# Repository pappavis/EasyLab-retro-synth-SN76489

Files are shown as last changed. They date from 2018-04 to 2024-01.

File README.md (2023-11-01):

## Chiptunes afspeel met Arduino ##
Lang gelede in die 1980's het ons grootgeword met 8-bit rekenaars soos BBC Micro B. Herleef die glorie en gebruik 'n BBC Micro geluidchip op Arduino | Raspberry Pi | Microbit.<br/>
<br/>
door: Michiel Erasmus<br/>
<br/>

## KiCAD 3d preview:
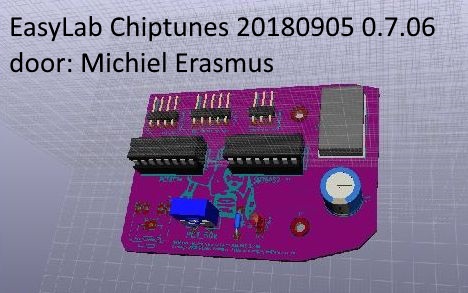
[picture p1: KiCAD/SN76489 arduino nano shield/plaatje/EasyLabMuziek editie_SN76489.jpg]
<br/>
<br/>

# User review
Buy online https://www.tindie.com/products/VliegendeVogel/arduino-soundcard-i2c-and-bbc-microbit-with-mml/

## Egte versie
Finale versie 0.7.06 <br>
<br/>

<br/>

## EasyLab4Kids
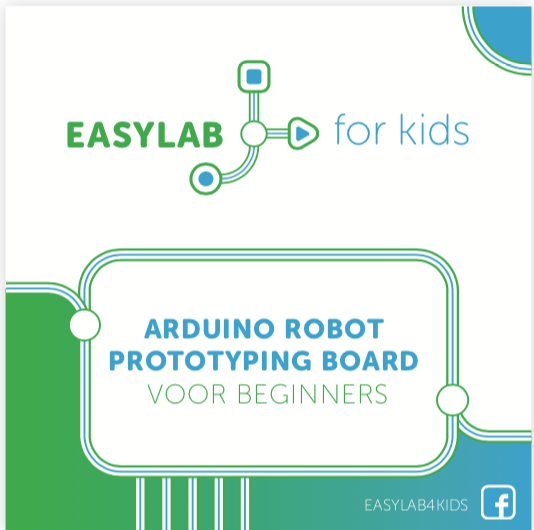
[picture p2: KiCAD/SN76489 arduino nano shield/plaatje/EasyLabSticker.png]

<br/><br/>
#e4kdenhaag<br/>

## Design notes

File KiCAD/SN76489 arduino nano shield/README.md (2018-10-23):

# EasyLab Muziek Editie #

Dit is 'n [Arduino][] shield vir [KiCad][] om muziek mee af te speel met gebruik van [SN76489][] geluids chip. <br/>
Die Sn76489 gebruik 'n 4.0000Mhz clock wat, of hardware clock osscilator kan wees, of gegenereerd met <a href="https://github.com/maxint-rd/FastPwmPin" target="_blank">FastPwmPin</a> van Maxint-RD.<br/>
<br/>
Features;<br/>
 - I2C aansluiting.<br/>
 - Gebruik arduino as clock op IO-poort 8.<br/>
 - Speel musiek af met MmlMusicPWM ook van MaxInt-RD.<br/>
 - Werkt met Arduino Nano, mega, Attiny85, D-MOS1 WiFi, Digispark USB, ESP8266-01 WiFi enz.



[KiCad]: http://www.kicad-pcb.org
[Arduino]: http://arduino.cc/
[SN76489]: https://nl.wikipedia.org/wiki/SN76489

## Hoe om te gebruik ##
 * Download Arduino IDE
 * Download en installeer Arduino biblioteek https://github.com/maxint-rd/mxUnifiedSN76489
 * Download en installeer Arduino biblioteek https://github.com/maxint-rd/mxUnifiedPCF8574
 * Met Arduino IDE. open voorbeeld Arduino/SN76489_met_PCF8574_arduino_clock_20180131.ino
  
## In deze argief ##

* KiCAD ontwerp
    * Die skema  en KiCAD model om 'n SN76489 geluidschip te gebruik.
* Printplaat schema
    * TODO -- gerber vir produksie
* 3D model
    * Voorbeeld van die model
* Bill of Materials
    * TODO
    
## License ##

Dit is 'n projek met GNU GPL version 3-lisensie.
usage of this PCB design should credit me as author. Thanks!

## Ontwikkelaar ##
2017-12-07 Origineel release<br/>
2017-06-02 Standalone I2C versie gebruikt.<br/>

<br/>\
#EasyLabMuziek #s4kdenhaag<br/>

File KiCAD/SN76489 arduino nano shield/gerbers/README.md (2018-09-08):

printplaat 20180602 0.6



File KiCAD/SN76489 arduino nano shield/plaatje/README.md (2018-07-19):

printplaat revisie 20180719 0.7.03

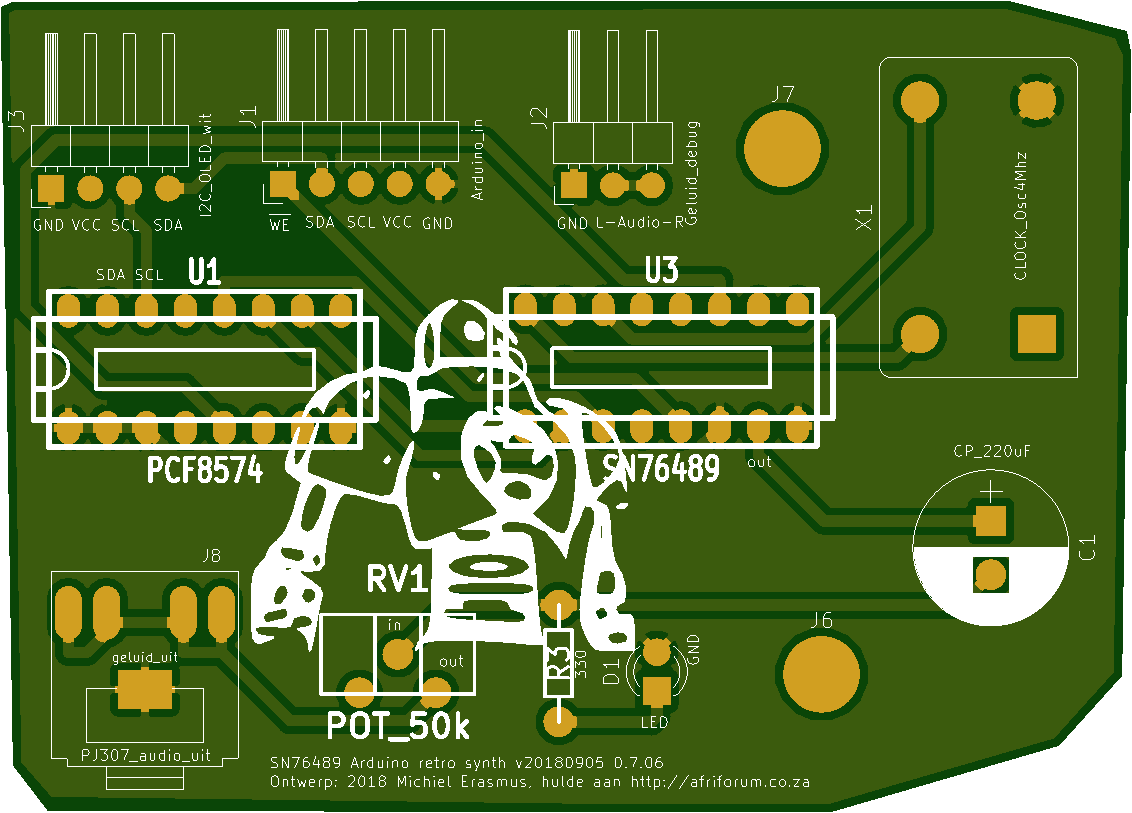
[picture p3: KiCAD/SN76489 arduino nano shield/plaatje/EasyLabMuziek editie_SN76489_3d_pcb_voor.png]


<br/>
<br/>
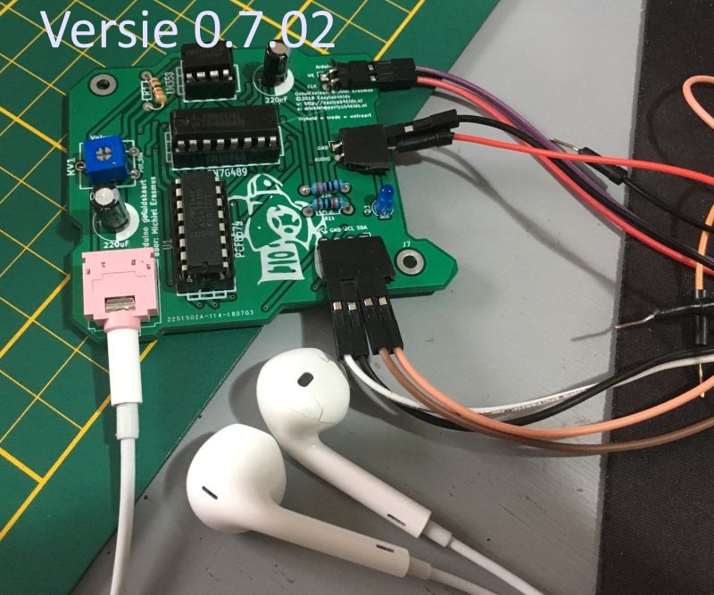
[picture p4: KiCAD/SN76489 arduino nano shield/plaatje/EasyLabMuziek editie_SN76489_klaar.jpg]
<br/>

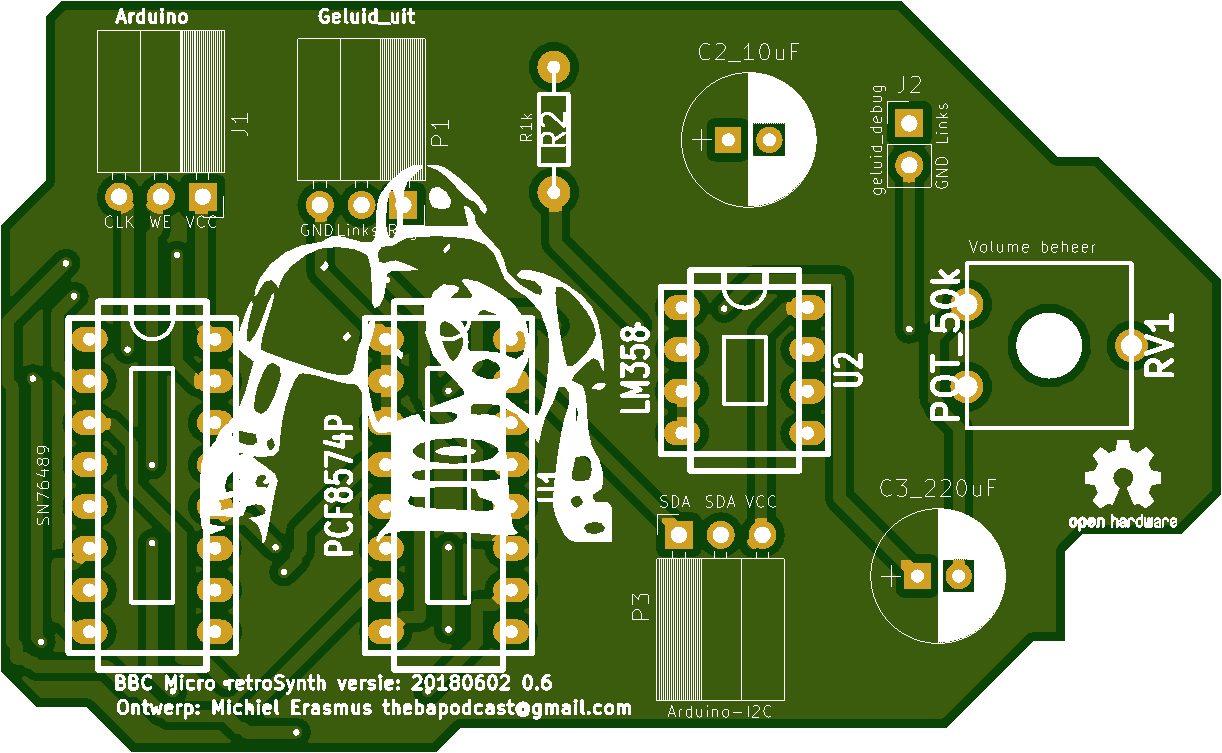
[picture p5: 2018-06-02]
KiCAD/SN76489 arduino nano shield/plaatje/EasyLabMuziek editie_SN76489_pcb_0.5_voor.png

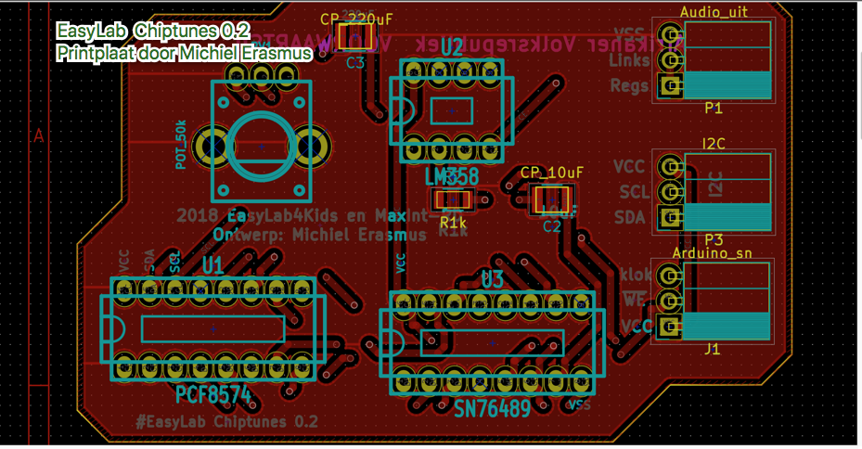
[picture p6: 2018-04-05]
KiCAD/SN76489 arduino nano shield/plaatje/EasyLabMuziek editie_SN76489_pcb.png

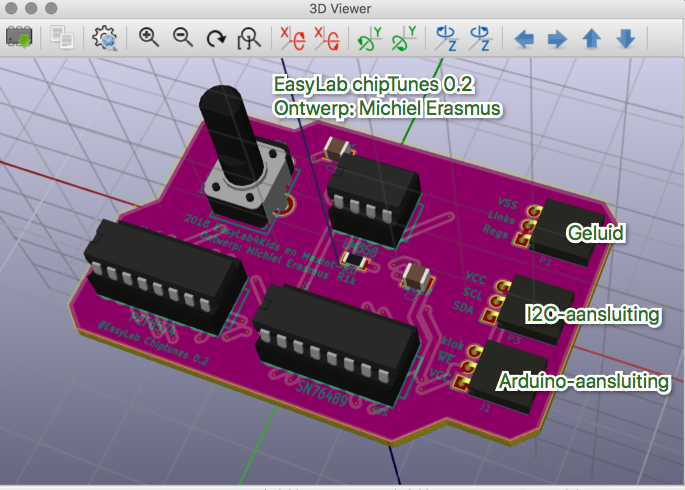
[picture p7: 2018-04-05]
KiCAD/SN76489 arduino nano shield/plaatje/EasyLabMuziek editie_SN76489_3d_0.2.png

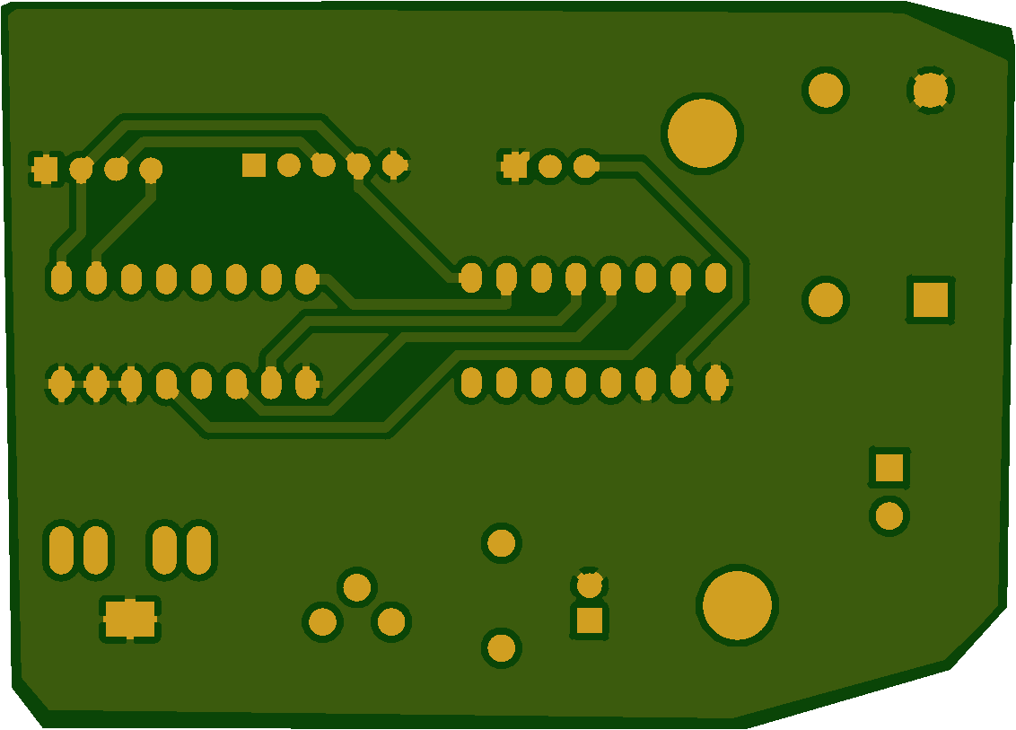
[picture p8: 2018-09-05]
KiCAD/SN76489 arduino nano shield/plaatje/EasyLabMuziek editie_SN76489_3d_pcb_agter.png

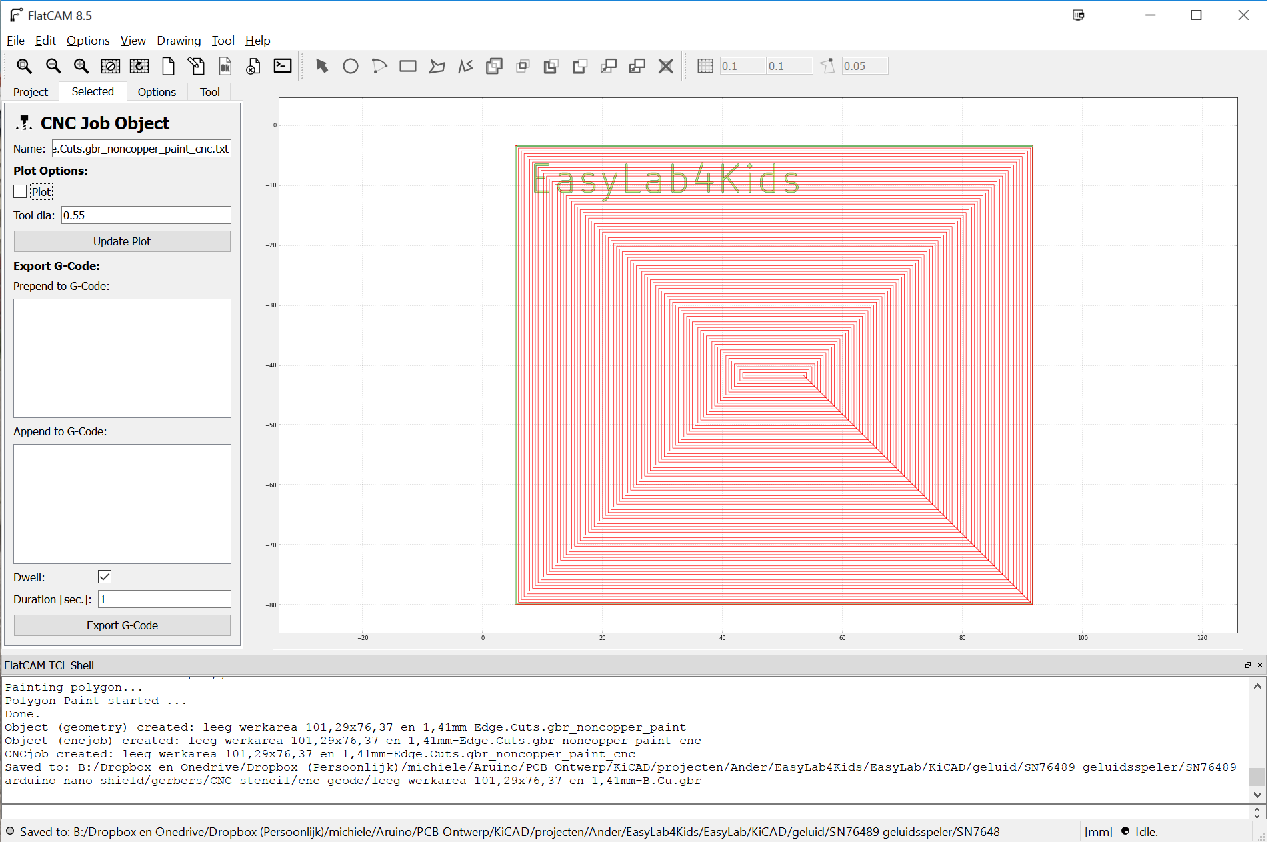
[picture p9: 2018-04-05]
KiCAD/SN76489 arduino nano shield/gerbers/CNC_stencil/leeg werkarea 101,29x76,37 en 1,41mm-Edge.Cuts.png

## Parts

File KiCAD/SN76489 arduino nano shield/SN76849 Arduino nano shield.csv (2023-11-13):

Id | Designator | Footprint | Quantity | Designation | Supplier and ref
1 | P1 | Jack_3.5mm_CUI_SJ1-3523N_Horizontal | 1 | TRS_JACK
2 | J5 | Sovjet_simpits_logo01 | 1 | LOGO
3 | U2 | DIP-8_W7.62mm | 1 | LM386
4 | J2 | PinHeader_1x03_P2.54mm_Vertical | 1 | audio_debug
5 | RV2 | Potentiometer_Bourns_3339P_Vertical | 1 | Pot_10k
6 | C2 | C_Disc_D3.4mm_W2.1mm_P2.50mm | 1 | 250uF
7 | J4 | PinHeader_1x06_P2.54mm_Vertical | 1 | ESP32Conn
8 | U1 | DIP-16_W7.62mm | 1 | PCF8574
9 | U3 | DIP-16_W7.62mm | 1 | SN76489
10 | J3 | PinHeader_1x04_P2.54mm_Horizontal | 1 | OLED_wit

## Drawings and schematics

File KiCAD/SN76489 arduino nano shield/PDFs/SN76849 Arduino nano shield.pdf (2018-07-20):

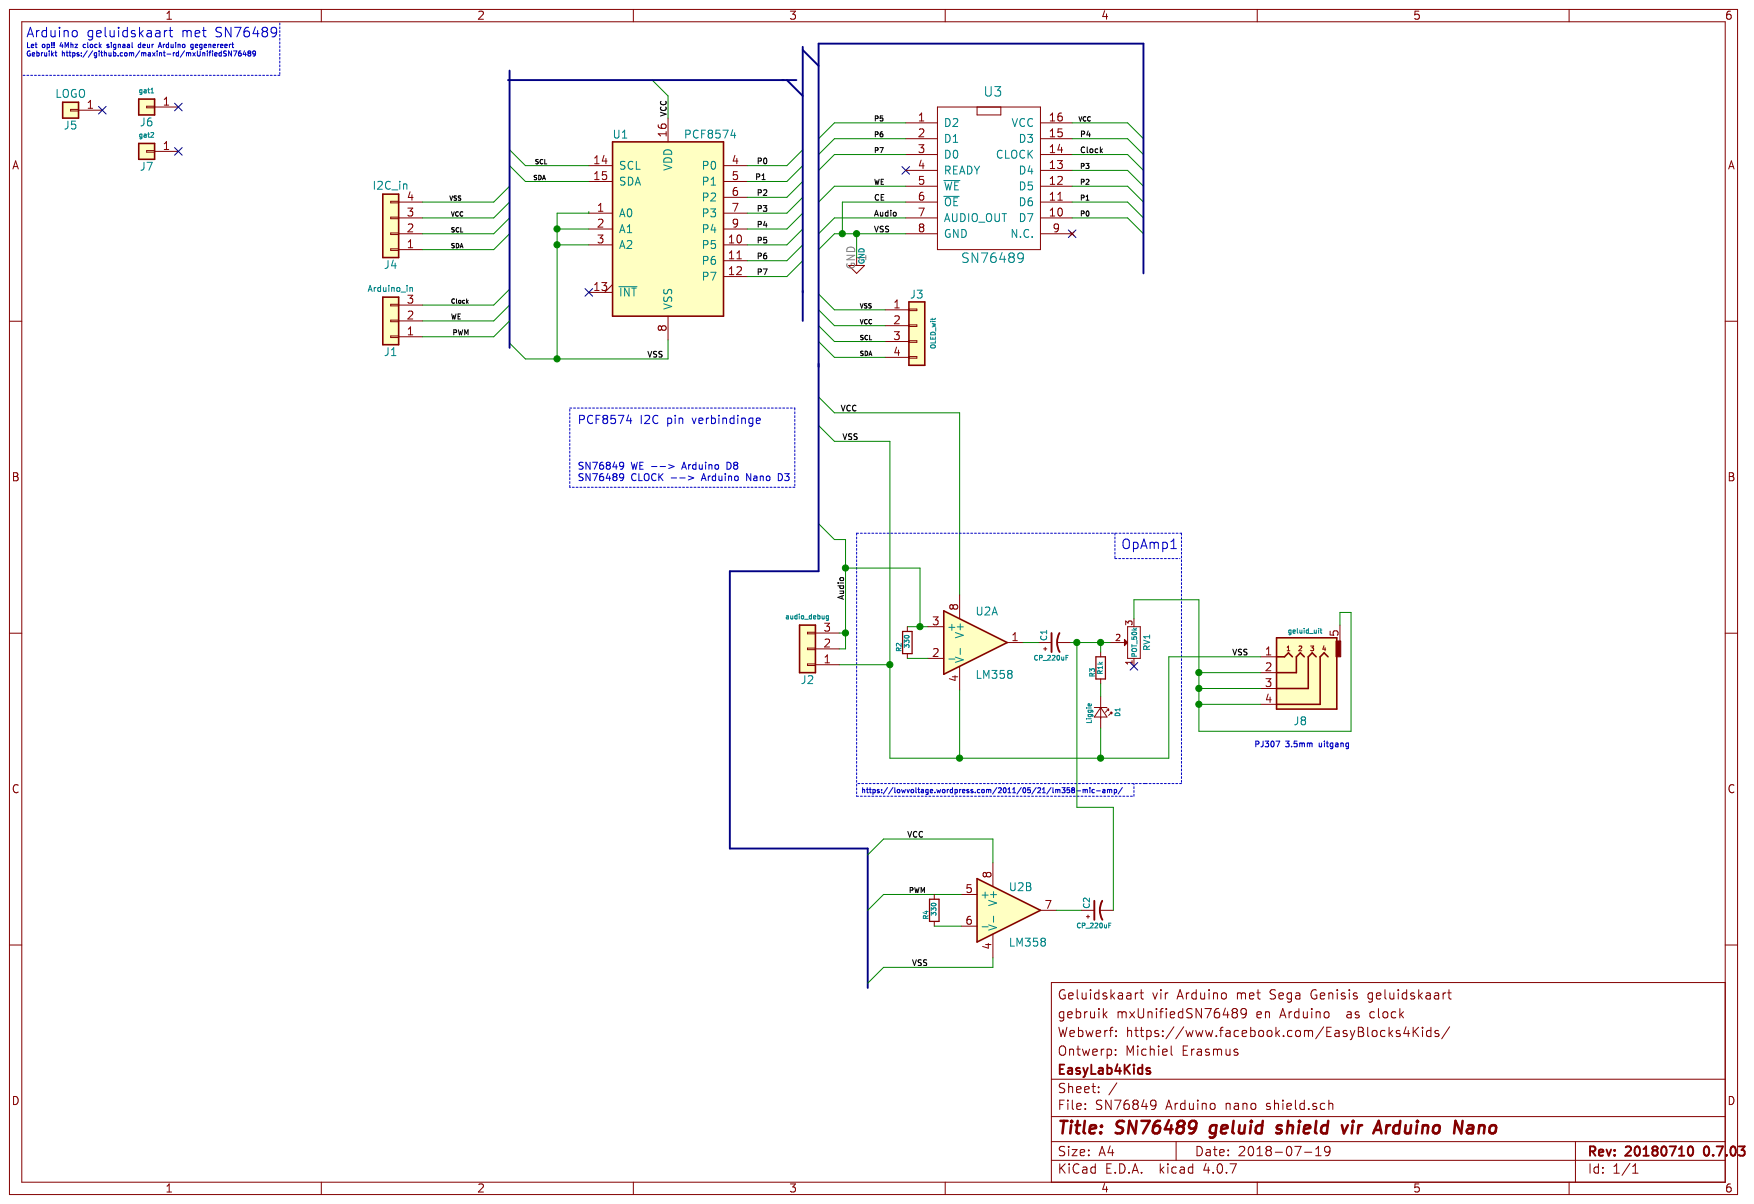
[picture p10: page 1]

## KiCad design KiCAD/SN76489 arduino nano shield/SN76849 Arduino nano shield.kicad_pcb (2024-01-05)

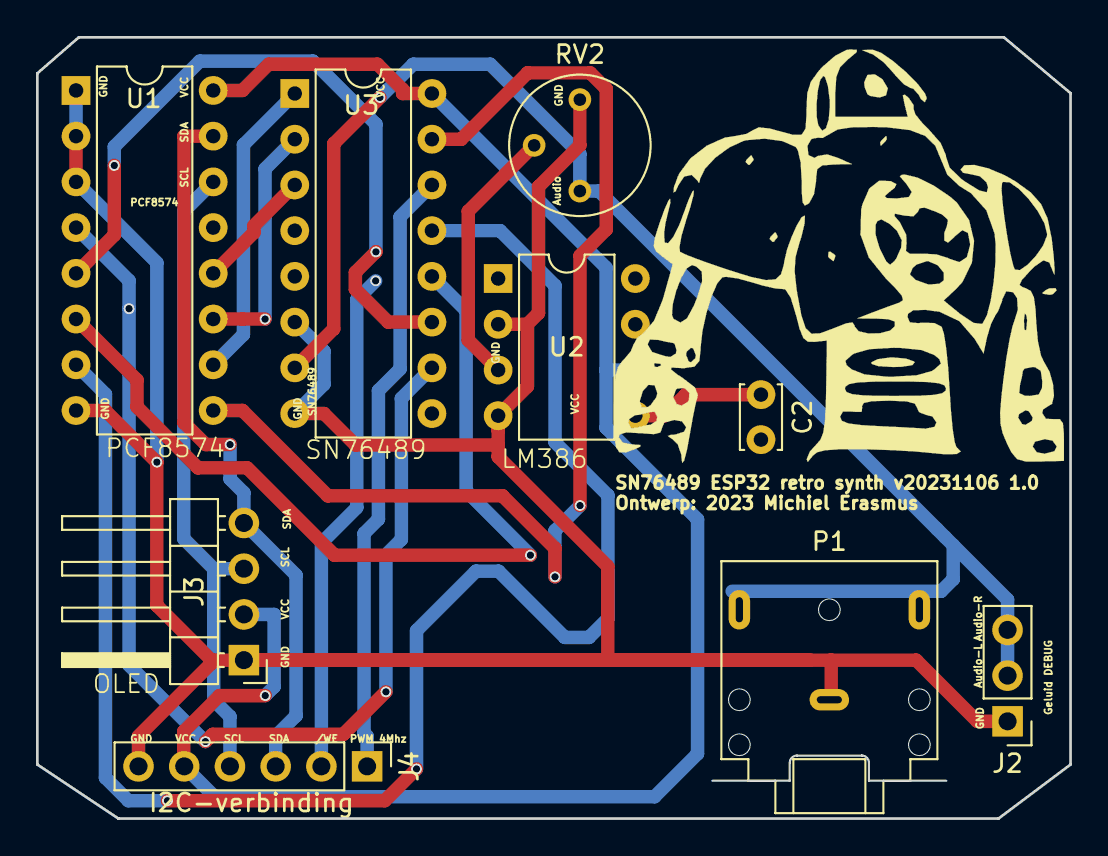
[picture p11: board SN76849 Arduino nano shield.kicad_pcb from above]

Board: 2 copper layers, 57.4 x 43.4 mm, 10 parts (0 on the bottom side), 16 nets.

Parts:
C2: 250uF; C_Disc_D3.4mm_W2.1mm_P2.50mm
J2: audio_debug; PinHeader_1x03_P2.54mm_Vertical
J3: OLED_wit; PinHeader_1x04_P2.54mm_Horizontal
J4: ESP32Conn; PinHeader_1x06_P2.54mm_Vertical
J5: LOGO; Sovjet_simpits_logo01
P1: TRS_JACK; Jack_3.5mm_CUI_SJ1-3523N_Horizontal
RV2: Pot_10k; Potentiometer_Bourns_3339P_Vertical
U1: PCF8574; DIP-16_W7.62mm
U2: LM386; DIP-8_W7.62mm
U3: SN76489; DIP-16_W7.62mm

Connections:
/Audio: J2.2, J2.3, RV2.1, U3.7 (AUDIO_OUT)
/Clock: J4.1, U3.14 (CLOCK)
/P0: U1.4 (P0), U3.10 (D7)
/P1: U1.5 (P1), U3.11 (D6)
/P2: U1.6 (P2), U3.12 (D5)
/P3: U1.7 (P3), U3.13 (D4)
/P4: U1.9 (P4), U3.15 (D3)
/P5: U1.10 (P5), U3.1 (D2)
/P6: U1.11 (P6), U3.2 (D1)
/P7: U1.12 (P7), U3.3 (D0)
/SCL: J3.3, J4.4, U1.14 (SCL)
/SDA: J3.4, J4.3, U1.15 (SDA)
GND: J2.1, J3.1, J4.6, RV2.3, U1.1 (A0), U1.2 (A1), U1.3 (A2), U1.8 (VSS), U2.2 (-), U2.4 (GND), U3.8 (GND)
unnamed: C2.1, U2.5
unnamed: RV2.2, U2.3 (+)
VCC: J3.2, J4.5, U1.16 (VDD), U2.6 (V+), U3.16 (VCC)

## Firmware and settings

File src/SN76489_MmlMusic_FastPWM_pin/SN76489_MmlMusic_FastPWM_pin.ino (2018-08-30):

// SN76489 retro synth voorbeeld
// versie: 20180807 0.7.05
// dit voorbeeld gebruik die Arduino om 4 Mhz clock signaal te genereren.
// sien afhanklikhede: https://github.com/maxint-rd?tab=repositories
// Arduino pin 4 = NotWE
// Arduino pin 3 = FastPWM Klok signaal

#define CLK_IOport  3
#define NotWEport   4

/*
 * mxUnifiedSN76489 MML Music
 * mxUnifiedSN76489 library example for Arduino IDE
 * 
 * Tbis example demonstrates playing MML music on the
 * SN76489 sound generator.
 * Using the mxUnifiedIO libraries, The SN76489 can be connected
 * to the MCU (e.g. Arduino Uno or ESP8266) via a shift
 * register or an I2C I/O expander.
 * 
 * For more information see: 
 *     https://github.com/maxint-rd/mxUnifiedSN76489
 *     https://github.com/maxint-rd/mxUnifiedIO
 *     https://github.com/maxint-rd/MmlMusic
 *
 * Made by MMOLE (@maxint-rd) 2017
 * 
 * For more MML music go to http://www.archeagemmllibrary.com/
 */

// Include header files for the used libraries
#include <mxUnifiedPCF8574.h>     // Use the PCF8574/8575 I/O-expander
//#include <mxUnified74HC595.h>   // use the 74HC595 shift-register
#include <mxUnifiedSN76489.h>
#include <MmlMusic.h>
// #include <FastPwmPin.h>

#if defined(MXUNIFIED_ATTINY)
  // ATtiny85 has no regular hardware serial. You can use TinyDebugSerial (TX=3) or software serial
  // For more info see  http://www.ernstc.dk/arduino/tinycom.html
  //#include <SoftwareSerial.h>
  //SoftwareSerial mySerial(4, 3); // RX, TX

  #include <TinyDebugSerial.h>
  TinyDebugSerial mySerial = TinyDebugSerial();   // Debug TX on PB3, no RX, only 9600, 38400 or 115200
  #define Serial mySerial
#endif

// When using a PCF8574/8575 I/O-expander, these connections and definitions can be used.
// Hardware I2C on ESP8266/D1-mini: SCL=GPIO5/D1, SDA=GPIO4/D2

// Use the PCF8574/8575 I/O-expander
mxUnifiedPCF8575 unio = mxUnifiedPCF8575(0x38);     // use the PCF875 I2C output expander on address 0x38

// define the pins used and initialize the mxUnifiedSN76489 object
// mxUnifiedSN76489 sound(&unio);     // use expanded pisn 0-7 for data, expanded pin 8 for NotWE
mxUnifiedSN76489 sound(&unio,NotWEport);   // use expanded pins 0-7 for data, MCU pin 4 for NotWE

// define the MML Music object
MmlMusic music;    // Note: don't use empty parenthesis () to use the (void) constructor; this will confuse the compiler.

// To play the tones on the SN76489 a callback functions are used.
// These are also used to display debug information on the serial console
// Resources are limited on the ATtiny85, so you may need to comment things out to preserve memory.
bool MyToneCallback(unsigned int frequency, unsigned long length, uint8_t nTrack, uint8_t nVolume)
{   // the tone callback is called on three occasions
  // 1. play a tone of certain frequency for specified length or indefinitely (len=0)
  // 2. wait for a certain period while tone or silence is played (freq=0, len=msec)
  // 3. stop playing (freq=0; len=0)
  
  if(frequency==0 && length==0)
  {
    //Serial.println(F("shhht"));
  }
  else
  {
    if(frequency>0)
    {
      Serial.print(nTrack);
      Serial.print(F("t:"));
      Serial.print(frequency);
      Serial.print(F(" "));
    }
    else
    {
      //Serial.print(F("wait"));
    }

/*
    if(length>0)
    {
      Serial.print(F(" len:"));
      Serial.print(length);
    }
*/  
  }

  if(frequency==0 && length==0)
  {   // stop specific track
    sound.noTone(nTrack);
  }
  else if(frequency>0)
  { // tone
    uint8_t nVol=15-(nVolume>>3);   // map volume: quiet=0 - loud=128 to quiet=15 - loud=0 
    sound.tone((float)frequency, nVol, nTrack);
  }
  return(true);    // return true to indicate callback made the tone and wants original playTone NOT to continue
}

 // Arduino core has no definition for FPSTR
// on ESP in wstring.h: #define FPSTR(pstr_pointer) (reinterpret_cast<const __FlashStringHelper *>(pstr_pointer))
#if !defined(FPSTR)
#define FPSTR(pstr_pointer) (reinterpret_cast<const __FlashStringHelper *>(pstr_pointer))
#endif

// Callback functions can also be set to indicate start or end of playing the music sequence
void MyPlayCallback(const char* mml, bool fUseFlash)
{ // Called prior to start of plsy. Note mml may point to PROGMEM string, depending on call to play or play_P
  // on ESP in wstring.h: #define FPSTR(pstr_pointer) (reinterpret_cast<const __FlashStringHelper *>(pstr_pointer))
  Serial.print(F("Play "));
  //Serial.println(fUseFlash ? FPSTR(mml) : mml); // cant use conditional expression with distinct pointer types
  if(fUseFlash)
    Serial.println(FPSTR(mml)); // Arduino core has no definition for FPSTR
  else
    Serial.println(mml);
}

void MyCompletionCallback(void)
{ // Called prior when done playing
  Serial.println(" Done!");
}

void delayR(uint16_t ms)
{ // without interrupts, normal delay will not continue Playing
  unsigned long ulEnd=millis()+ms;
  while(millis()<ulEnd)
  {
    if(music.isPlaying())
      music.continuePlaying();
    delay(1);   // on ESP we need to yield to feed the watchdog
  }
}

/**/
// Star Wars – The Force theme (two tracks)
const char szPlay[] PROGMEM="v127t100l4o4 r g>c2d.d16+f16d+2<g.l8g>c4.dd+<d+>l12d+cgf2.<g4>c4.l8dd+.<g16>g.d+16>c2<c4l12d+dcg4&gd+c<g4g8.g16>c2"
                              ",v127t100l8o3 r4cg>cd+fdc<gcg>cd+dc<bgcg>cd+ggc<gf>cfa>c4<d<gcg>cd+gd+<a+4g+>cd+g+4.<g+4g>cd+gc4<b4c2 r";
/**/
/*
// Star Wars Theme (three tracks)
// short version for ATtiny85: const char szPlay2[] PROGMEM="T107o6c16<b16a16g16>c16<b16a16g16>c16<b16a16g16>f16e16d16c16c16<b16a16g16>c16<b16a16g16>c16<b16a16g16>f16e16d16c16c16<b16a16g16>c16<b16a16g16>c16<b16a16g16>f16e16d16c16c16<b16a16g16>c16<b16a16g16>f16e16d16c16<g16.g16g16.>c2g2f16.e16d16.>c2<g4f16.e16d16.>c2<g4f16.e16f16.d4<g4g16.g16g16.>c2g2f16.e16d16.>c2<g4f16.e16d16."
const char szPlay[] PROGMEM="T107o6c16<b16a16g16>c16<b16a16g16>c16<b16a16g16>f16e16d16c16c16<b16a16g16>c16<b16a16g16>c16<b16a16g16>f16e16d16c16c16<b16a16g16>c16<b16a16g16>c16<b16a16g16>f16e16d16c16c16<b16a16g16>c16<b16a16g16>f16e16d16c16<g16.g16g16.>c2g2f16.e16d16.>c2<g4f16.e16d16.>c2<g4f16.e16f16.d4<g4g16.g16g16.>c2g2f16.e16d16.>c2<g4f16.e16d16.>c2<g4>d16.c16<b16.>c4<c16.c16c16.c4"
",T107o4b8r8>c8r4c8r8c8r8c8r8c8c8r8c8r8<b8r8>c8r4c8r8c8r8c8r8c8c8r8<g16.g16g16.e2>c2<a4>e4f4c4<a4>e4f4c4d16.c+16d16.<b4d4d16.d16d16.e2>c2<a16.r8r32>e2c4<a4>e4f4c4g16.r8r32<g4c16.c16c16.c4"
",T107o3c8r8 e8r4f8r8f8r8e8r8g8f8r8f8r8c8r8e8r4f8r8f8r8e8r8g8f8r8<g16.g16g16.>c4<b4a4g4f4e4d4c4f4e4d4c4>a+16.a16a+16.g4c4c16.c16c16.c4<b4a4g4a4g4f4e4f4e4d4c4g16.g16g16.>c4<c16.c16c16.c4";
/**/

void setup()
{
  Serial.begin(115200);
  Serial.println(F("mxUnifiedSN76489 MML Music"));

 // FastPwmPin::enablePwmPin(CLK_IOport, 4000000L, 50);  // generate 4Mhz klok signaal
  
  // initialize the sound chip
  //unio.setBitOrder(LSBFIRST);   // reverse connections on 74HC595 (could also be done by changing wires)
  unio.begin();     // start using the mxUnified74HC595 I2C shift register
  sound.begin();

  // set callback functions
  music.setPlayCallback(MyPlayCallback);
  music.setToneCallback(MyToneCallback);
  music.setCompletionCallback(MyCompletionCallback);

  // Start playing some music (if impatient use the short tune of the lower line).
  music.play_P(szPlay);
  //music.play_P("T180 L8 CDEC. r CDEC. r EFG. r EFG. r GAGFEC. r GAGFEC. r L4 C<A>C. r C<A>C.");
}


// the loop function runs over and over again forever
void loop()
{
  if(music.isPlaying())
    music.continuePlaying();
  else
  {
    music.play_P(PSTR("T240 O4 L64 AB>C, T240 O4 L32 CBA V0 A \0\0")); // give a short beep
    delayR(1000);   // without interrupts, delay will make playing to not continue on time
  }
}

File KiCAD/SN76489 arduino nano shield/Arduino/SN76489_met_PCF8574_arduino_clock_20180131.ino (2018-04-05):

// 20170131 michiel uitprobeersel.

// SN76489_test example.
// Example by Maxint R&D for driving the SN76489 via a 74HC595 shift register
// using the mxUnifiedIO libraries.
//
// For more information and used libraries see
//    https://github.com/maxint-rd/mxUnifiedIO
//    https://github.com/maxint-rd/mxUnified74HC595
//    https://github.com/maxint-rd/mxUnifiedSN76489
//
//
#include <mxUnified74HC595.h>   // use the 74HC595 shift-register
#include <mxUnifiedPCF8574.h>    // Use the PCF8574/8575 I/O-expander
#include <mxUnifiedSN76489.h>
#include <FastPwmPin.h>

#if defined(MXUNIFIED_ATTINY)
  // ATtiny85 has no regular hardware serial. You can use TinyDebugSerial (TX=3) or software serial
  // For more info see  http://www.ernstc.dk/arduino/tinycom.html
  //#include <SoftwareSerial.h>
  //SoftwareSerial mySerial(4, 3); // RX, TX

  #include <TinyDebugSerial.h>
  TinyDebugSerial mySerial = TinyDebugSerial();   // Debug TX on PB3, no RX, only 9600, 38400 or 115200
  #define Serial mySerial
#endif

// Hardware SPI pins:
//   ATmega328: SS=10, MOSI=11, SCLK=13
//   ATtiny85:  SS=0, MOSI=1, SCLK=2
//   ESP8266:   SS=15, MOSI=13, SCLK=14
//   Suggested pins ESP-01:   SS=3 (RX), MOSI=2, SCLK=0

// create the 74HC595 output object
//mxUnified74HC595 unio = mxUnified74HC595();                  // use hardware SPI pins, no cascading
//mxUnified74HC595 unio = mxUnified74HC595(2);               // use hardware SPI pins, two cascaded shift-registers (slightly slower, but more pins)
// mxUnified74HC595 unio = mxUnified74HC595(10, 11, 13);      // alternative software SPI pins: SS, MOSI, SCLK, no cascading (slow, but pin-freedom)
//mxUnified74HC595 unio = mxUnified74HC595(10, 11, 13, 2);   // alternative software SPI pins: SS, MOSI, SCLK, two  cascaded shift-registers (even slower, but pin-freedom)
//mxUnified74HC595 unio = mxUnified74HC595(3, 2, 0);      // alternative software SPI pins for ESP-01: SS, MOSI, SCLK, no cascading (slow, but pin-freedom)
//mxUnified74HC595 unio = mxUnified74HC595(0, 1, 2);      // alternative software SPI pins for Attiny85: SS, MOSI, SCLK, no cascading (slow, but pin-freedom)

// Use the PCF8574/8575 I/O-expander
// mxUnifiedPCF8575 unio = mxUnifiedPCF8575(0x38);     // use the PCF875 I2C output expander on address 0x38
mxUnifiedPCF8574 unio = mxUnifiedPCF8574(0x38);     // use the PCF875 I2C output expander on address 0x38
//  Hardware I2C on ESP8266/D1-mini: SCL=GPIO5/D1, SDA=GPIO4/D2

// define the pin used and initialize the mxUnifiedSN76489 object
// mxUnifiedSN76489 sound(&unio);    // use expanded pin 0-7 for data, expanded pin 8 for NotWE
mxUnifiedSN76489 sound(&unio,8);    // use MCU pin 4 for NotWE (eg when using only 8-bit expander)

void setup()
{
  Serial.begin(115200);
  Serial.print(F("mxUnifiedSN76489 SN76489_test"));

  // Generate clock signal on pin D3
  // ATmega328/168 (Uno/Nano/Pro Mini): pin D3 or pin D11 (D11 toggle only)
  FastPwmPin::enablePwmPin(3, 4000000L, 50);

  // initialize the sound chip
  //  unio.setBitOrder(LSBFIRST);   // reverse connections on 74HC595 (could also be done by changing wires)
  unio.begin();     // start using the mxUnified74HC595/I2C expander
  //  unio.begin(1000000L);      // for I2C one can specify fast I2C or when experiencing noise, try slower I2C. Pullups may help too.

  for(int teller1 = 0; teller1 < 8; teller1++)
  {
    unio.digitalWrite(teller1, HIGH);
    delay(100);
    unio.digitalWrite(teller1, LOW);
    delay(100);
  }
  
  sound.begin();    // will call SilenceAllChannels();

  // sound a beep
  Serial.println(F("beep()"));
  sound.beep(100);
  delay(100);
  sound.beep(100);
  delay(100);
  sound.beep(100);
  delay(900);

  // make a two-voice bell sound
  Serial.println(F("bell"));
  sound.tone(440.0f,0,SN76489_CHN0);
  delay(100);
  for(int n=0; n<15; n++)
  {
    sound.volume(n, SN76489_CHN0);
    if(n==8) sound.tone(220.0f,0,SN76489_CHN1);
    delay(50);
  }
  for(int n=0; n<15; n++)
  {
    sound.volume(n, SN76489_CHN1);
    delay(50);
  }
  sound.stop();
  delay(500);
 
  // sound a siren
  Serial.println(F("siren"));
  for(int n=0; n<10; n++)
  {
    for(float ftTone=100.0; ftTone<4000.0; ftTone+=10)
    {
      sound.tone(ftTone, n);
      delay(1);
    }
  }
  sound.stop();

  // sound some noise
  Serial.println(F("noise"));
  for(int n=0; n<10; n+=3)
  {
    for(float ftTone=0.0; ftTone<600.0; ftTone+=10)
    {
      sound.tone(ftTone, n, SN76489_CHN3);
      delay(100);
    }
  }
  sound.stop();
  delay(500);

  Serial.println(F("loop"));
}

void loop()
{
  // lets sound a small tick every second
  // sound.beep(5);

  for(int n=0; n<10; n++)
  {
    for(float ftTone=100.0; ftTone<4000.0; ftTone+=10)
    {
      sound.tone(ftTone, n);
      delay(1);
    }
  }
  sound.stop();
    
  delay(1500);
  
}

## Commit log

2018-04-05 eerste commit
    [SN76849 Arduino nano shield-B.Cu.gbr, SN76849 Arduino nano shield-B.Mask.gbr, SN76849 Arduino nano shield-B.Paste.gbr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]
2018-04-05 PCF8574 netlist name bygewerkt na SN76489
    [SN76849 Arduino nano shield.sch]
2018-06-02 Printplaat 20180601 0.5 laat maak
    [SN76849 Arduino nano shield-B.Cu.gbr, SN76849 Arduino nano shield-B.Mask.gbr, SN76849 Arduino nano shield-B.Paste.gbr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]
2018-06-02 Printplaat 20180601 0.6 i2C silkS SDA toegevoegd
    [SN76849 Arduino nano shield-B.Cu.gbr, SN76849 Arduino nano shield-B.Mask.gbr, SN76849 Arduino nano shield-B.Paste.gbr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]
2018-06-18 toevoeging OpAmp schema en PCB 20180617 0.7
    daar is nog een bug. Op printplaat capacitor C1 posetief niet
    verobonden!
    [SN76849 Arduino nano shield.kicad_pcb, SN76849 Arduino nano shield.sch]
2018-06-24 DERC fails opgelost 20180617 0.7.01
    'n paar nets ontbreekte conneksies op de printplaat.
    [SN76849 Arduino nano shield-B.Cu.gbr, SN76849 Arduino nano shield-B.Mask.gbr, SN76849 Arduino nano shield-B.Paste.gbr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]
2018-06-24 toevoeging OpAmp schema en PCB 20180617 0.7.01
2018-06-28 revisie 20180624 0.7.01 naar China
    silkscreen toegevoegd
    [SN76849 Arduino nano shield-B.Cu.gbr, SN76849 Arduino nano shield-B.Mask.gbr, SN76849 Arduino nano shield-B.Paste.gbr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]
2018-07-10 EasySynth SN87489 synth 0.7.01 printplaatversie
    [SN76849 Arduino nano shield.kicad_pcb, SN76849 Arduino nano shield.sch]
2018-07-19 20180719 0.7.03 OLED
    Groot bugfix;
    POTmeter verbinding
    LM358 nu dual op
    PWM pin is verbonde met LM358 out2
    Geluidsuitgang debug in stereo
    OLED skerm I2c toegevoegd.
    [SN76849 Arduino nano shield-B.Cu.gbr, SN76849 Arduino nano shield-B.Mask.gbr, SN76849 Arduino nano shield-B.Paste.gbr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]
2018-07-20 bij20180719 0.7.03 OLED
    [SN76849 Arduino nano shield.sch]
2018-09-03 Upgrade project naar KiCAD 4.0.0
    [SN76849 Arduino nano shield-2018-09-03-14-51-59.sch, SN76849 Arduino nano shield.sch]
2018-09-05 versie 20180905 0.7.06
    LM358 opAmp wasverwyderd,
    Dip-14 Xtal clock 4Mhz toegevoegd.
    [SN76849 Arduino nano shield-B.Cu.gbr, SN76849 Arduino nano shield-B.Mask.gbr, SN76849 Arduino nano shield-B.Paste.gbr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]
2018-09-08 versie 20180905 0.7.06
    [SN76849 Arduino nano shield-B.Cu.gbr, SN76849 Arduino nano shield-B.Mask.gbr, SN76849 Arduino nano shield-B.Paste.gbr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]
2023-02-28 Use CHATGPT to write to the SN76489 via I2C
2023-02-28 the first 15 seconds of the chiptune Commando by Rob Hubbard and play it using 3 analoge pins on a ESP32
    This code snippet generates a simple square wave with a frequency of 440Hz and a duty cycle of 50%, and outputs it to 3 different analog pins (pins 26, 27, and 32). It then defines a melody (the firs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
    Note that this code is only a simple example and may need to be modified to produce the desired sound and to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
2023-03-01 Plays midi files on SN76489 using I2C
2023-04-07 sn67489 I2c van https://github.com/Kyuchumimo/micropython-sn76489
2023-10-26 Bijgewerkt naar KiCAD 7.0
    [SN76849 Arduino nano shield.kicad_sch]
2024-01-05 PCB gerbers naar jlcpcb.com
    [SN76849 Arduino nano shield-B.Cu.gbr, SN76849 Arduino nano shield-B.Mask.gbr, SN76849 Arduino nano shield-B.Paste.gbr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]
2025-02-18 COnverted to KiCAD8
    [SN76849 Arduino nano shield.kicad_sch]

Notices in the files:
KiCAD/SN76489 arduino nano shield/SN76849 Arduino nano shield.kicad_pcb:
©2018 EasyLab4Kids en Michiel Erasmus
